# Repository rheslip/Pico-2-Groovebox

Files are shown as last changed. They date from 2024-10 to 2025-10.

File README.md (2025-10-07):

# Pico 2 Groovebox
 Sample player/groovebox based on RP2350

Oct 2025 - added step editor and .stl files for 3D printed enclosure. SD interface changed from SPI to SDIO which improved flie loading speed a lot. Tweeks to the sensitivity of some of the MPR121 keypad keys have been added. I had issues with keypresses being detected too easily or not at all. Still not completely resolved but much improved. Various other bug fixes and enhancements.

demo and tutorial https://www.youtube.com/watch?v=hEJh2LgJkRc&t=5s 
 
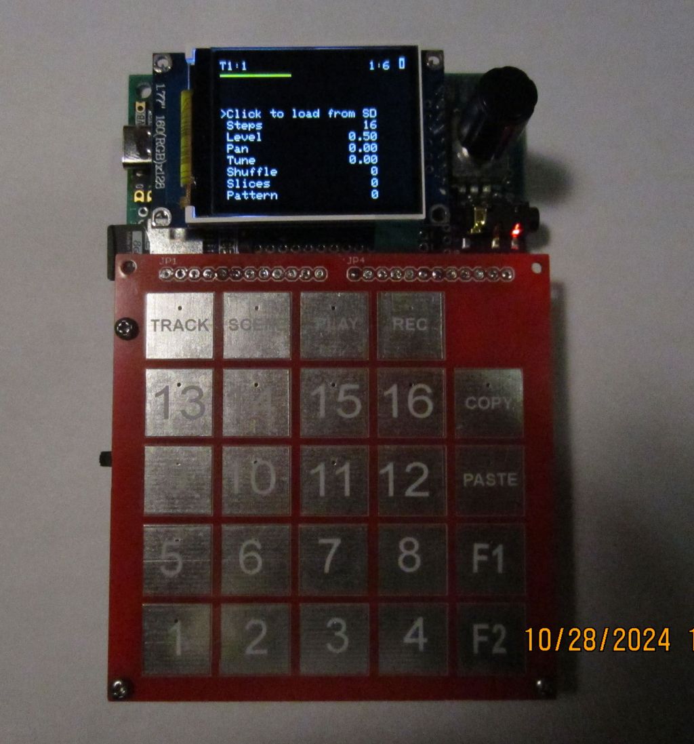
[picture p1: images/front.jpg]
Front
 
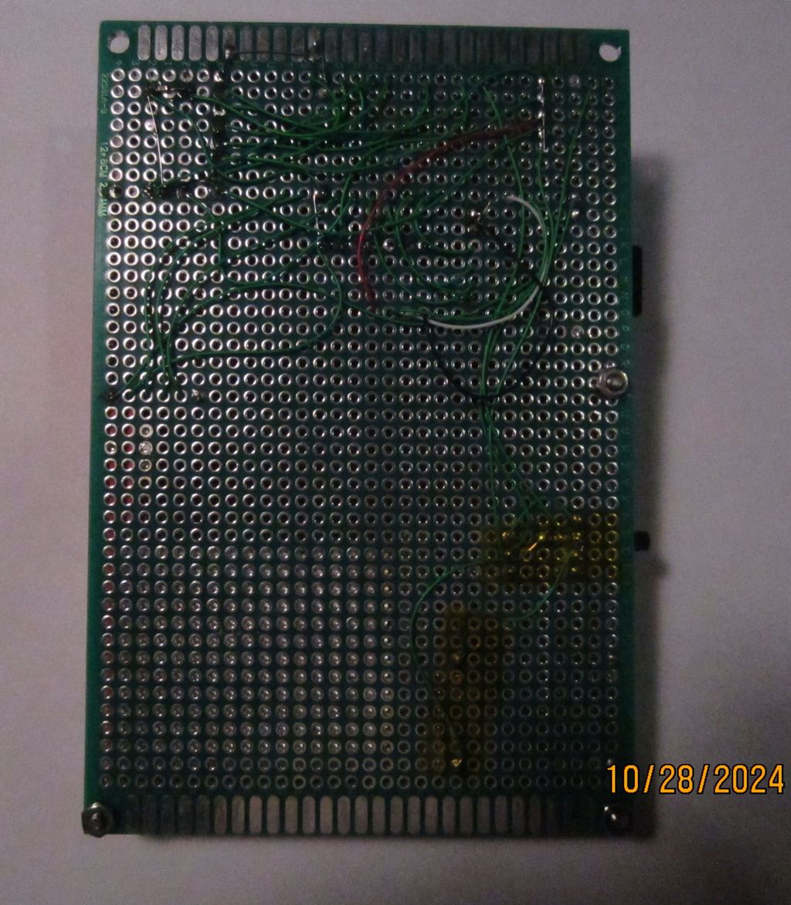
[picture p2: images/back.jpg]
Back
 
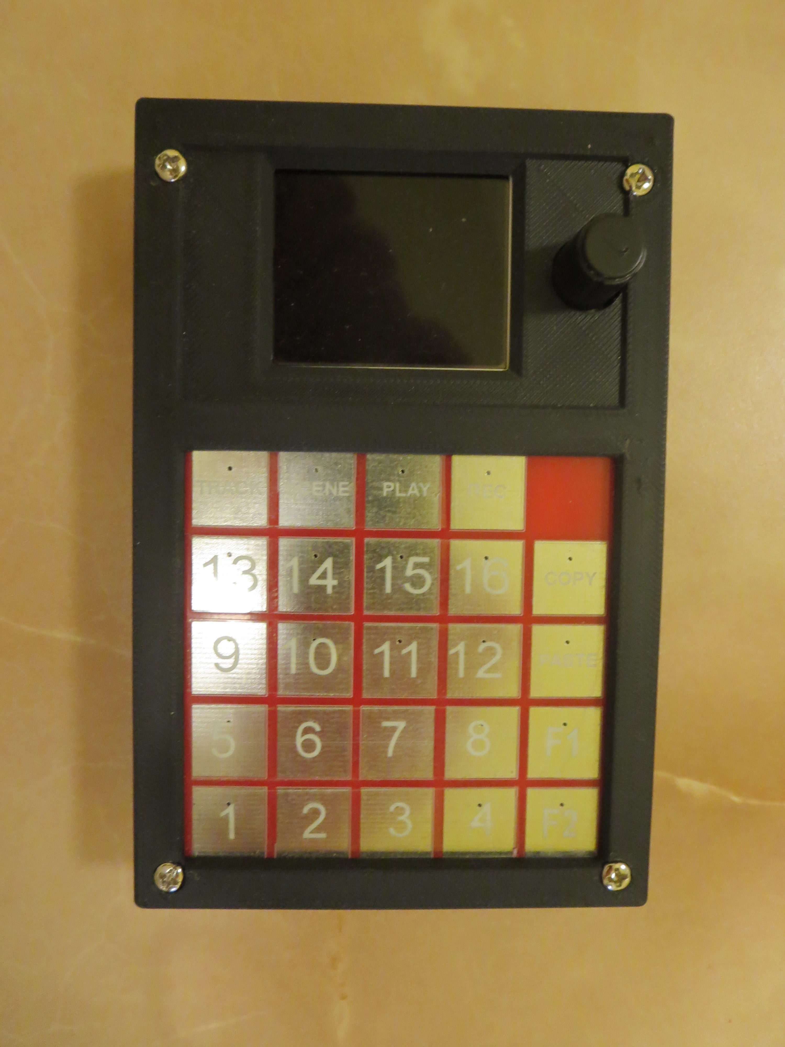
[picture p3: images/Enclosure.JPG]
New 3D Printed Enclosure
  
 
**Hardware components used**

Pimoroni Pico 2+ with 8mb PSRAM (for sample storage)

Generic PCM5102A DAC module from AliExpress

160x128 ST7735 color TFT display

Encoder with switch

24 pad touch keyboard PCB - gerbers are in the hardware directory. $4 including shipping for 5 PCBs from JLCPCB.com

2x MPR121 touch sensor modules from AliExpress

Micro SD breakout board **Note that the latest version of the code uses SDIO which is much faster**

**Optional:**

LiPo battery - I used 1500mah for approx 8 hours use

LiPo charger module from AliExpress

Power switch

3V to 5V stepup regulator from AliExpress

3d Printed Case - .stl files in the hardware section. Design is for a build on 80x120mm perfboard available on Aliexpress or Amazon. No doubt will need tweeking unless your layout is exactly like mine.

There is no schematic but it should be pretty obvious how to wire the modules to the RP2350 board if you look at IO.h in the source code.

**Overview**

Pico 2 Groovebox is a flexible sample player + groovebox with 16 tracks and 16 scenes. Samples can be oneshots or loops. You can play samples with the keypad, play loops, record clips and use drum trigger patterns. Each track has a sequencer which triggers a sample to play. Sequences can be from 1 to 128 steps but normally you would set tracks up as multiples of 16 steps (1 bar). 

It is helpful to think of tracks and scenes as a matrix with columns as tracks and rows as scenes. This setup is similar to Ableton and most grooveboxes. You can record a clip in every cell of this 16x16 matrix ie up to 144 clips, subject to memory limitation which is currently 512 total notes per track. 

The basic workflow is to select a track by holding the TRACK key and select the track using the number pads. Use the Track menus to load a .WAV file sample to a track from the SD card - this saves it in PSRAM for playback (SD is way too slow for direct playback). You can then record a clip (a sequence of sample triggers) by tapping the REC key and touching the the numbered keypads. Holding the REC key will erase the sequence. To change tracks hold the TRACK key and select another track using the number pads.

You can record up to 16 clips per track. Clips are organized by scenes ie rows of clips. Hold the SCENE key to select a scene using the number pads. Selecting a scene will launch all clips on that row of the clip matrix.

Tap the PLAY button to start or stop playback of all clips in the current scene. Hold the PLAY button to start playback in Song mode (described below).

When the sequencers are running you can play samples using the keypad to jam over the current scene, record sequences while the scene is playing, switch scenes and even record in song mode. 

Internally, clips are stored as MIDI sequences. I may consider adding MIDI I/O to the Pico 2 Groovebox so it could be used as a 16 channel MIDI recorder/sequencer.

**Track Screen and Menus**

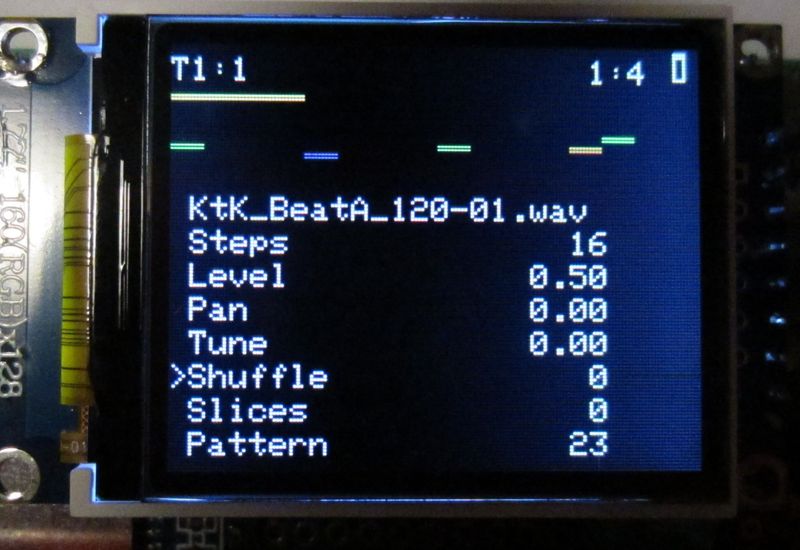
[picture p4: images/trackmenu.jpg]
trackmenu
 

The top line of the screen shows the currently selected Track:Scene, Song and Record indicators when enabled, and a Bar:Step indicator. On the far right is a simple battery level display.

Below that is a sequencer progress bar which indicates where the sequencer is. This is helpful when recording.

Below the progress bar is a small piano roll display showing the notes recorded on the track. If random velocities are enabled (see below) the color of the steps will range from Magenta (low velocity) to Red (highest velocities).

Below the piano roll is a parameter menu for each track for loading a sample, setting the track length in steps, setting the volume and pan, adjusting the tuning of the sample, adjusting the track shuffle timing, enabling or disabling sample slicing, and to adjust the pattern generator parameters.

**Setup Menu**

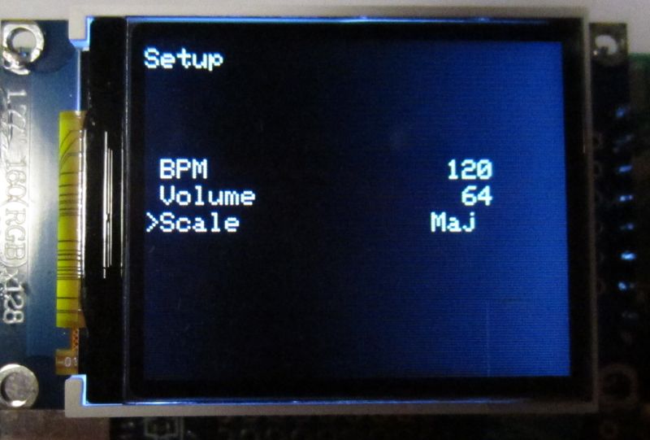
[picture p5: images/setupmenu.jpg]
setupmenu
 
 
Hold the TRACK key and turn the encoder to scroll through tracks 1-16. The first menu past track 16 is the Song chain menu (below). The next menu is Setup which allows selection of BPM, master volume and the musical scale to use on the numbered keys.

**Scales**

There are currently ten musical scales to select from. Selecting a scale changes the layout of the numbered keys. Key 9 plays the sample at its nominal pitch. Playing keys above key 9 will raise the pitch of the sample according to the selected scale. e.g. if the selected scale is chromatic each numbered key above 9 increases the pitch by one semitone. Likewise, keys below 9 reduce the pitch according to the selected scale.

Note that sample pitch and sample tuning are accomplished by a resampling algorithm so higher pitches will play for a shorter time and lower pitches become longer in duration. ie no timestretching going on here!

**Pattern Generator**

The pattern generator is an alternate way of loading trigger patterns into the sequencer. There are currently fifty three 16 bit trigger patterns organized from fewest triggers with pattern 0 having no triggers to pattern 53 which triggers on every sequencer step. Trigger patterns include some common drum patterns and some Euclidean patterns. If the sequencer length is longer than 16, the pattern will be repeated till the sequencer is full. If the sequencer length is less than 16 the trigger pattern will be shortened to the sequencer length. This is a handy way to chop a pattern off - shorten the sequence, load a trigger pattern and then lengthen the sequence.

The Pattern Shift parameter shifts the trigger pattern right one bit at a time, adding 16 more patterns to each of the basic trigger patterns.

The Pattern Offset parameter generates a series of random pitch offsets in the range selected in the menu. These offsets are added to the base note of the sample, quantized to the current scale and inserted into the sequencer. This results in a random melody in the current scale using the current pattern. 

The Level Offset parameter generates a series of random velocity offsets in the range selected in the menu. These offsets are added to velocity of the sample to give the sequence some random volume variations. The Level Offset parameter is scaled such that its maximum value (16) results in a random velocity range of 0 to 127.

The Autorandomizer parameter when "On" will re-randomize the pitch offsets and velocity offsets when the sequencer loops back to the first step. Huge fun when used with the sample slicer on loops!

Note that the pattern generator overwrites the sequencer clip with a new generated sequence when any of its parameters are changed. This means you can record more steps over a pattern but you can't add a pattern on top of a recorded clip.

**Step Editor**

The pattern step editor is accessed by pressing the F1 key - "Edit" will appear at the top of the display. A green cursor will appear under the first step on the piano roll. The number to the right of "Edit" is the step the cursor is on - rotate the encoder to change steps. To edit a step press the encoder - the cursor will turn red indicating we are entering or editing a note at this step. If there is no note at the step one will automatically be inserted with MIDI note 60 - the MIDI note number appears beside the step number at the top of the screen. Turn the encoder to change the note pitch (+-1 octave). To remove a note, turn the encoder until the note dissappears off the top or bottom of the piano roll display. Press the encoder to exit note entry mode. Press F1 again to exit the step editor. 

**Clip/Scene Cut and Paste**

To copy a clip, press the Copy key while that clip is on the screen. Select a different clip (using Track and or Scene keys as above) and press the Paste key to copy the sequence to that clip.

To copy an entire scene, hold the Scene key and press the Copy key to copy the current scene. Select a new scene using the Scene key and the numbered keys and press Paste to paste into the new scene.

**Sample Slicer**

The Slices parameter in the track menu controls if slicing is off (slices=0) or the number of uniform sample slices to use up to a maximum of 16. Sample slices are mapped to the numbered keys - if the number of slices is less than 16 the slice pattern repeats over the numbered keys. Slices can be played on the keypad, recorded as a clip or sequenced with the pattern generator. If using the pattern generator, the Sample Offset is used to select which sample is played on active sequencer steps. ie if Sample Offset is 0, the pattern will only include the first slice, if Sample Offset is 1 it will randomly include slice 0 or slice 1 etc.

Sample Slicer + Pattern Generator Autorandomizer = a lot of fun! 

**Song Chain**

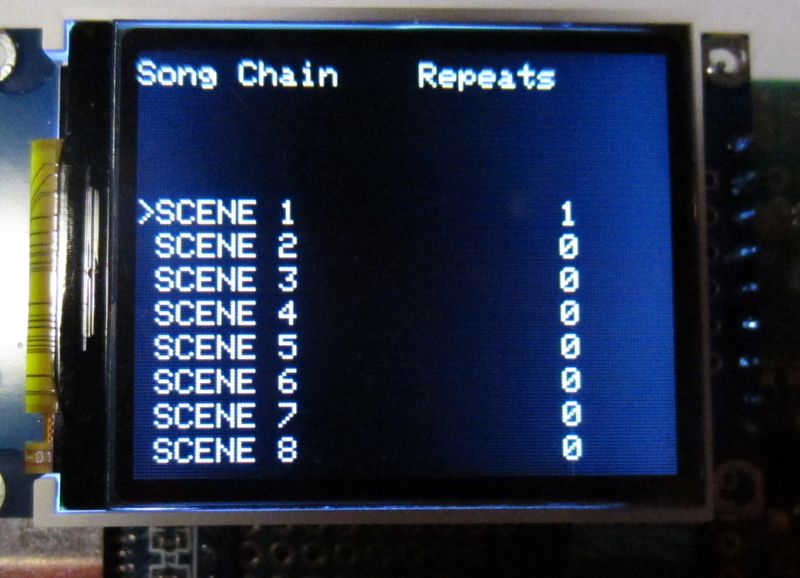
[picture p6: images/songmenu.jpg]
songmenu
 
 
As described above, the first menu when scrolling past track 16 is the Song Chain. The Song Chain is a list of scenes and the number of repeats for each  scene. By default all scene counts are 0 except for Scene 1 which will always have a minimum repeat count of 1. A song chain is set up by selecting the number of times you would like each scene to repeat. If the count is 0, that scene is skipped. At the the end of the chain the song will restart at Scene 1. To play the song, hold the Play key until the "SONG" indicator on the top line of the display is on. To turn song mode off, hold the Play key until the "SONG" indicator goes off.

Note: In song mode, a scene is completed/counted down when ALL clips arrive on the last step at the same time. e.g. if one of the tracks is set to a sequence length of 64 and the others are 16 steps, the other tracks will be repeated 4 times and when the 64 step sequence ends the scene counter will be counted down. If we have a track with a sequence length of 16 and another with a length of 15, it will take 16 iterations for the two tracks to arrive at the last step at the same time. If you add another track with 14 steps, its going to take a long time for them to all arrive at the last step at the same time! In general you should keep sequence lengths multiples of 16 or 1 bar.

**A Word on SD Cards**

I don't think its mandatory for micro SD card to work with a SPI interface. I have a small assortment of 4gb, 8gb and 16gb micro SD cards and very few of them seem to work with SPI. **Note that the latest version of the code uses SDIO to access the SD card**. Make sure the card is formatted as FAT16 or FAT32. All samples **MUST** be under a directory in the root named "Samples". As mentioned before it is suggested you organize your samples in subdirectories with no more than 50 or so samples to keep loading time to a minimum. The maximum path length is 200 characters so don't go too crazy on the directory and sample name lengths.

**FAQ**

How do you compile the source? I used arduino 2.3.2 with Arduino Pico v 4.1. You will need Adafruit graphics library, the ST 7735 driver, and probably some other libs I've forgotten. The rest of the stuff is in the source tree. I started with the Adafruit FifteenStep MIDI recorder library but I had to modify it a lot so I renamed it SixteenStep and its included in the library directory.

Why not have sequencer length set up in bars? I debated this and actually had it set up with bars at one point. I opted for the flexibility of having sequences be any length (up to 128). Its useful for ambient stuff or jamming when you want things to sound similar but not repeat exactly. Set two drum tracks to different lengths for example and the rhythm will change as the beats change relative to each other on every loop.

Why the pattern generator? I had it set up as just a recorder and then quickly realized its hard (for me anyway) to play the pads to record exactly on step 1, which you want if you have multiple scenes (so scene changes are in sync). The pattern generator makes it easy to place triggers where you want them and relative to each other.

Is the code stable? Not completely. It crashes now and then but I've used it for hours on end with no glitches. Still working on those pesky bugs...

Why is loading files so slow? **Its MUCH better with the new SDIO interface**. Still not as fast as I'd like but very usable.

What file formats will it read? 16 and 24 bit, 44hkz, 22khz, stereo or mono .WAV files. It converts everything to 22khz mono internally. I suggest you organize your samples into directories with no more than 50 or so samples per directory to minimize loading time.

Why do you use 22khz mono internally? To minimize memory use. With 8mbytes RAM you can load about 190 seconds of 22khz mono samples vs only 47 seconds with 44khz stereo. Use the pan control for fake stereo - it actually sounds really good even at 22khz.

Why don't you do a PCB? It would probably have to be two boards to work mechanically. I'm not that great at PCB layout - maybe somebody else would take this on if I do a schematic in Kicad?

What are the F1 and F2 keys for? TBD. I'm thinking of adding some more features like track mute and solo

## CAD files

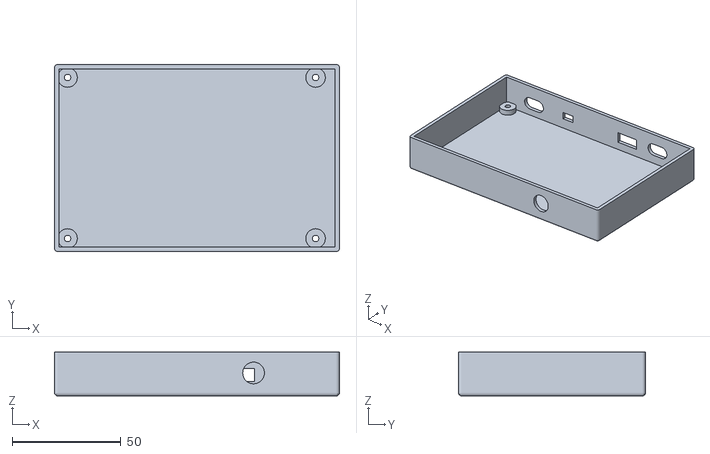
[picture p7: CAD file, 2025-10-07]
hardware/Enclosure/Base.stl
131.0 x 86.0 x 20.2

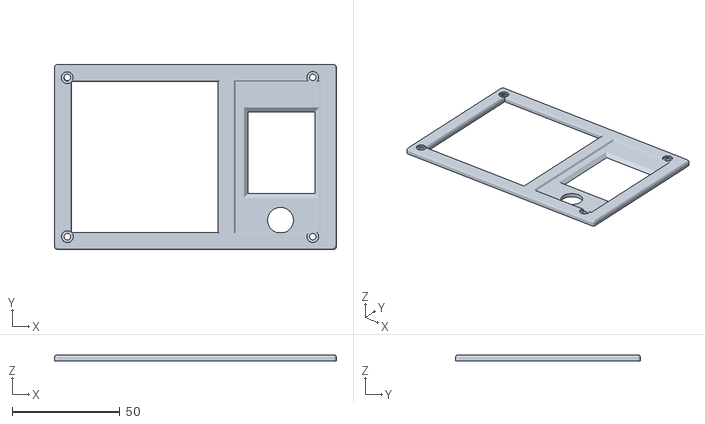
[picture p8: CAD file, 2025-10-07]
hardware/Enclosure/Top.stl
131.0 x 86.0 x 3.00

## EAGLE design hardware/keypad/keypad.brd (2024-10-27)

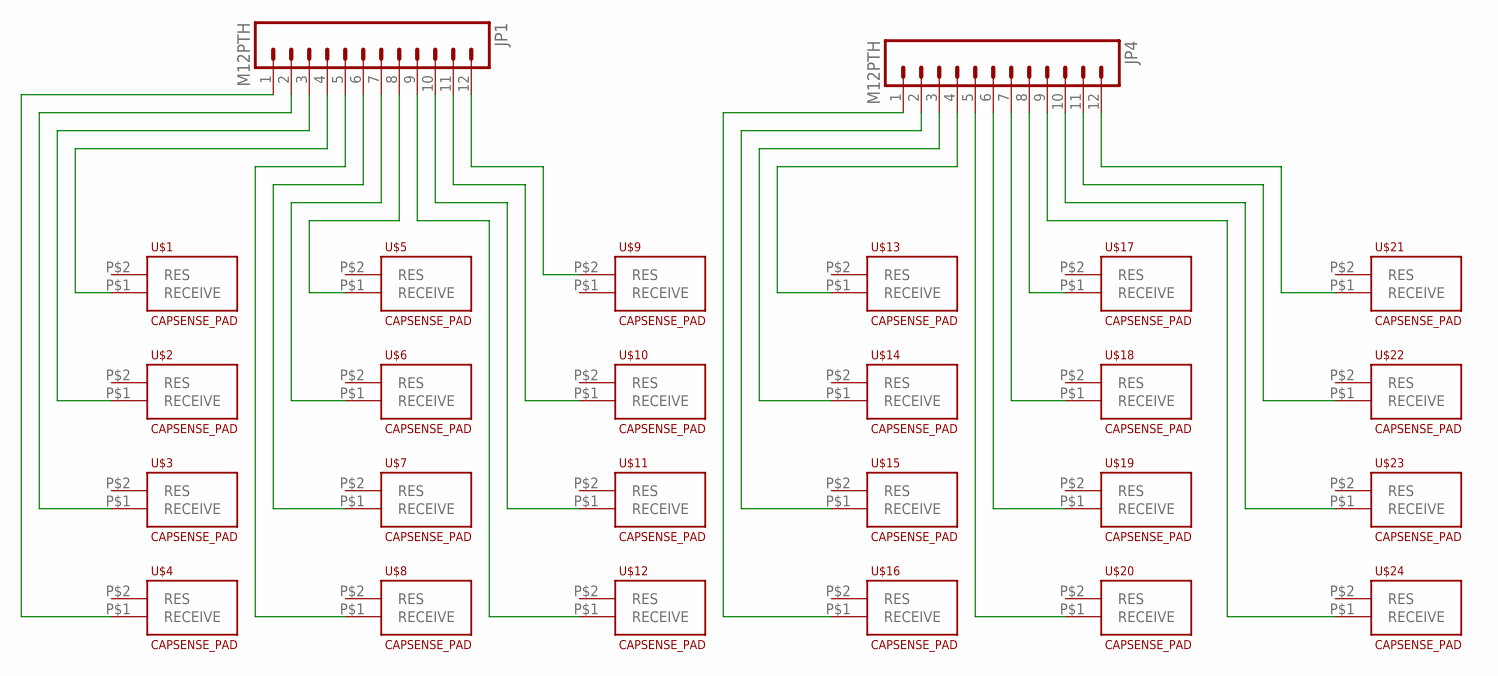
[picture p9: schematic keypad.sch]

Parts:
JP1, JP4: M12PTH; 1X12
U$1, U$2, U$3, U$4, U$5, U$6, U$7, U$8, U$9, U$10, U$11, U$12, U$13, U$14, U$15, U$16, U$17, U$18, U$19, U$20, U$21, U$22, U$23, U$24: CAPSENSE_PAD

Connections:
unnamed: JP1.1, U$4.P$1 (RECEIVE)
unnamed: JP1.2, U$3.P$1 (RECEIVE)
unnamed: JP1.3, U$2.P$1 (RECEIVE)
unnamed: JP1.4, U$1.P$1 (RECEIVE)
unnamed: JP1.5, U$8.P$1 (RECEIVE)
unnamed: JP1.6, U$7.P$1 (RECEIVE)
unnamed: JP1.7, U$6.P$1 (RECEIVE)
unnamed: JP1.8, U$5.P$1 (RECEIVE)
unnamed: JP1.9, U$12.P$1 (RECEIVE)
unnamed: JP1.10, U$11.P$1 (RECEIVE)
unnamed: JP1.11, U$10.P$1 (RECEIVE)
unnamed: JP1.12, U$9.P$2 (RES)
unnamed: JP4.1, U$16.P$1 (RECEIVE)
unnamed: JP4.2, U$15.P$1 (RECEIVE)
unnamed: JP4.3, U$14.P$1 (RECEIVE)
unnamed: JP4.4, U$13.P$1 (RECEIVE)
unnamed: JP4.5, U$20.P$1 (RECEIVE)
unnamed: JP4.6, U$19.P$1 (RECEIVE)
unnamed: JP4.7, U$18.P$1 (RECEIVE)
unnamed: JP4.8, U$17.P$1 (RECEIVE)
unnamed: JP4.9, U$24.P$1 (RECEIVE)
unnamed: JP4.10, U$23.P$1 (RECEIVE)
unnamed: JP4.11, U$22.P$1 (RECEIVE)
unnamed: JP4.12, U$21.P$1 (RECEIVE)

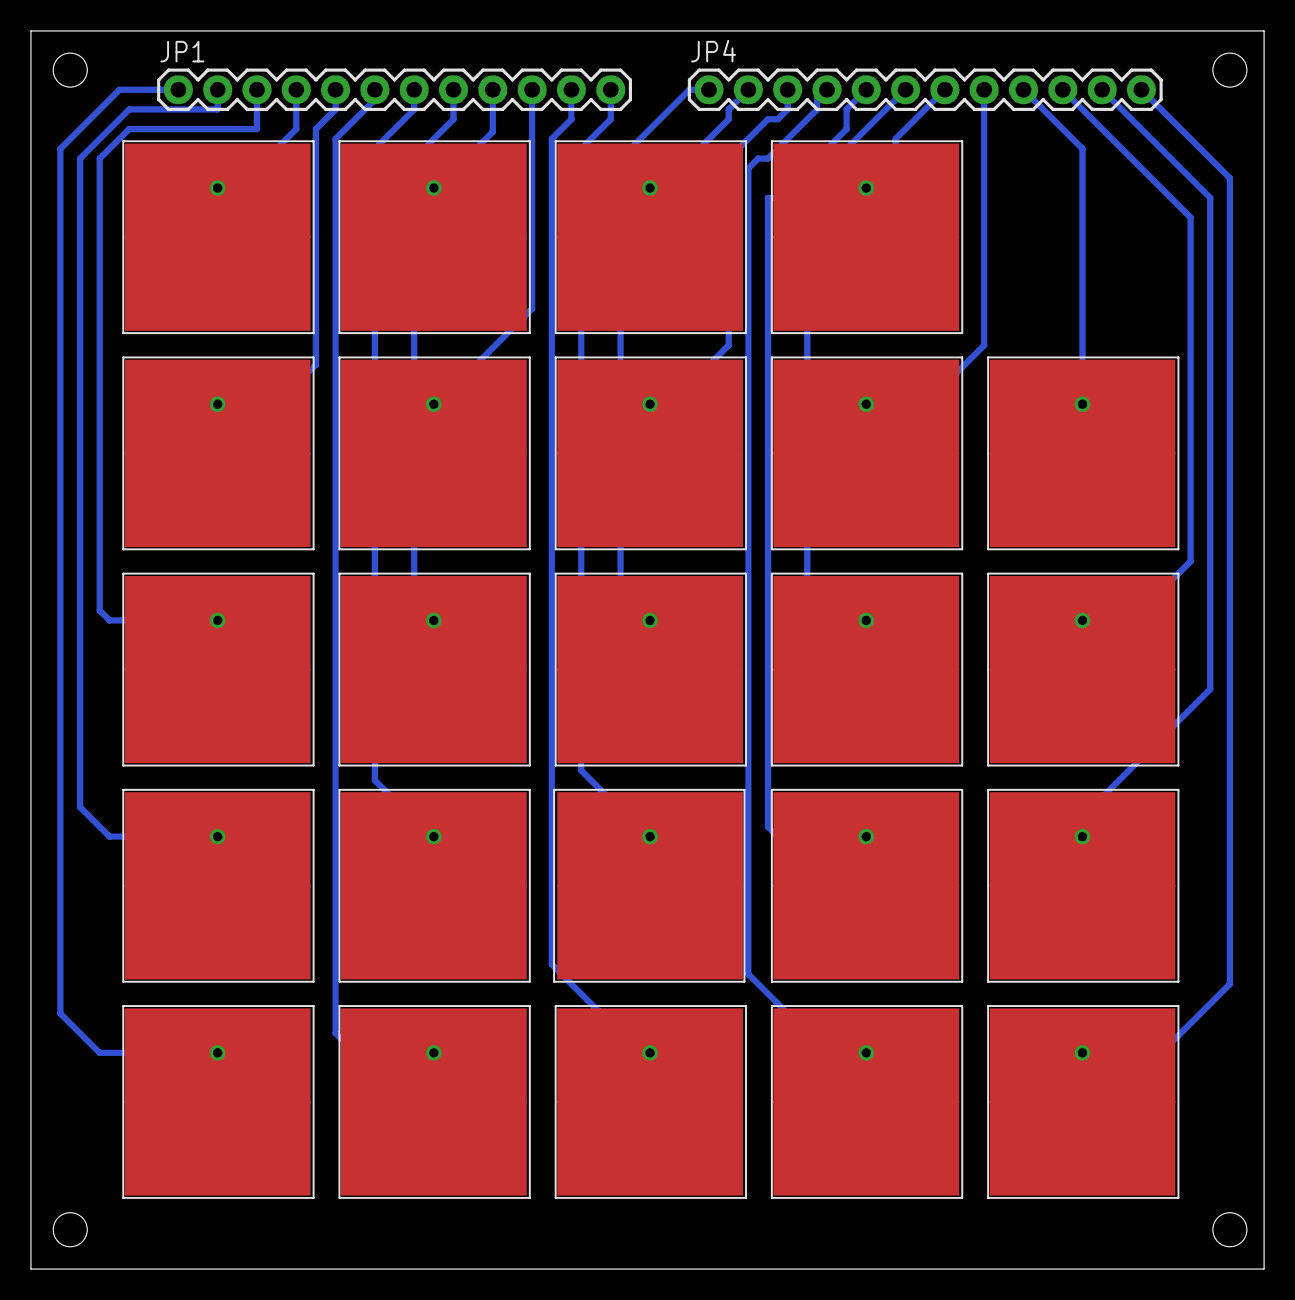
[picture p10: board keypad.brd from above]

Board: 2 copper layers, 79.7 x 80.0 mm, 26 parts (0 on the bottom side), 24 nets.

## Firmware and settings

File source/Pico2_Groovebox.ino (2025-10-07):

// Copyright 2019 Rich Heslip
//
// Author: Rich Heslip 
//
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
// See http://creativecommons.org/licenses/MIT/ for more information.
//
// -----------------------------------------------------------------------------
//
// 
// sample player/looper inspired by Jan Ostman's ESP8266 drum machine http://janostman.wordpress.com
// will play a 22khz sample file converted to a header file in the appropriate format
// Feb 3/19 - initial version on ESP8266
// Jan 2023 - ported code to Pi Pico so I can use it on a 16mb flash version
// July 24 - this version modded to run on my new groovebox HW - added recording, tracks, scenes, song mode, sample slicing etc
// Sept 2024 - ported to Pimoroni Pico 2 + board with 8mb PSRAM and SD card - can load samples from SD now. 160x128 Color TFT display. added a per track pattern generator

#include <Arduino.h> 

//#include <WiFi.h>
//#include <i2s.h>
//#include <i2s_reg.h>
//#include <pgmspace.h>
//#include "driver/i2s.h"
//#include "freertos/queue.h"
#include <Wire.h>
#include "SdFat.h"
#include "sdios.h"

#include <SPI.h>
//#include <SD.h>

#include <Adafruit_GFX.h>
#include <Adafruit_ST7735.h> // Hardware-specific library for ST7735
//#include <Adafruit_SSD1306.h>
//#include <SH1106.h>
//#include "MIDI.h"
#include "io.h"
#include <I2S.h>
//#include "RPi_Pico_TimerInterrupt.h" // fails on RP2350 after a while
#include <hardware/timer.h>
#include <hardware/irq.h>
#include "Clickencoder.h"
#include "Adafruit_MPR121.h"
#include "SixteenStep.h"
#include "pico/multicore.h"
#include "drumpatterns.h"

#define DEBUG // to get serial debug info

#ifndef _BV
#define _BV(bit) (1 << (bit)) 
#endif

// Try to select the best SD card configuration.
#if defined(HAS_TEENSY_SDIO)
#define SD_CONFIG SdioConfig(FIFO_SDIO)
#elif defined(RP_CLK_GPIO) && defined(RP_CMD_GPIO) && defined(RP_DAT0_GPIO)
// See the Rp2040SdioSetup example for RP2040/RP2350 boards.
#define SD_CONFIG SdioConfig(RP_CLK_GPIO, RP_CMD_GPIO, RP_DAT0_GPIO)
#elif ENABLE_DEDICATED_SPI
#define SD_CONFIG SdSpiConfig(SD_CS_PIN, DEDICATED_SPI, SPI_CLOCK)
#else  // HAS_TEENSY_SDIO
#define SD_CONFIG SdSpiConfig(SD_CS_PIN, SHARED_SPI, SPI_CLOCK)
#endif  // HAS_TEENSY_SDIO


// SD_FAT_TYPE = 0 for SdFat/File as defined in SdFatConfig.h,
// 1 for FAT16/FAT32, 2 for exFAT, 3 for FAT16/FAT32 and exFAT.
#define SD_FAT_TYPE 3

#if SD_FAT_TYPE == 0
SdFat sd;
File file;
#elif SD_FAT_TYPE == 1
SdFat32 sd;
File32 file;
#elif SD_FAT_TYPE == 2
SdExFat sd;
ExFile file;
#elif SD_FAT_TYPE == 3
SdFs sd;
FsFile file;
#else  // SD_FAT_TYPE
#error Invalid SD_FAT_TYPE
#endif  // SD_FAT_TYPE

// Try max SPI clock for an SD. Reduce SPI_CLOCK if errors occur.
//#define SPI_CLOCK SD_SCK_MHZ(50)
// #define SPI_CLOCK SD_SCK_MHZ(25)

#define MONITOR_CPU1  // define to enable 2nd core monitoring
//#define HW_DEBUG  // for debug pin usage

//Adafruit_SH1106 display(OLED_DC, OLED_RESET, OLED_CS);
Adafruit_ST7735 display = Adafruit_ST7735(TFT_CS, TFT_RS, TFT_RESET);
#define WHITE ST77XX_WHITE
#define BLACK ST77XX_BLACK
#define RED ST77XX_RED
#define RED2 0xF804
#define LIGHTGREEN 0x03e0
#define GREEN ST77XX_GREEN
#define BLUE ST77XX_BLUE 
#define CYAN ST77XX_CYAN
#define MAGENTA ST77XX_MAGENTA
#define YELLOW ST77XX_YELLOW
#define ORANGE ST77XX_ORANGE


#define PSRAM_ADDR 0x11000000
#define PSRAM_SIZE 0x00800000  // 8 Mbytes

//#define SAMPLERATE 11025 
#define SAMPLERATE 22050
//#define SAMPLERATE 44100
#define PMALLOC_CHUNK 131072 // hopefully minimizes memory fragmentation 

#define MIDDLE_C 60 // MIDI note for middle C
#define HIGHEST_NOTE 76 // upper note for editor
#define LOWEST_NOTE 43 // lower note for editor
#define NOTE_DEADZONE 4 // range of notes above highest and below lowest that will result in note being turned off in editor
#define DEFAULT_LEVEL 64  // default MIDI velocity

#define NTRACKS 16  // 
#define NSCENES  16 // works best with the keypad
#define NUM_VOICES NTRACKS
#define MAX_STEPS FS_MAX_STEPS // max number of notes per sequencer
#define SEQUENCER_MEMORY 2048  // memory per sequencer (bytes)
//#define SEQUENCER_MEMORY sizeof(SixteenStepNote)*MAX_STEPS // FifteenStep can record polyphonic but not using that 
#define STEPS_PER_BAR 16
#define TEMPO    120 // default tempo
#define CLIPS_COMPLETE ((1<<NSCENES)-1) // bitmap of clips that are on last step

// Keeps track of the last pins touched
// so we know when buttons are released
uint32_t lasttouched = 0;
uint32_t currtouched = 0;
#define RECBUTTON_HOLD_TIME 500 // time in ms for rec button hold to erase
#define TRANSPORT_BUTTON_HOLD_TIME 500 // time in ms for play button hold to start song mode

// remap pads from MPR121 readings which are not in order to desired keypad position
// top row - track,scene, start/stop, record
// next 4 rows x 4 columns keypad 0-15
// right column copy, paste
// ** note to self - uncomment the pad number code in loop() below and press PAD0 (Number pad 1) and enter its bit number as the definition for PAD0. etc etc
#define NPADS 24 // total number of pads on keypad
/*
#define PAD0 4   // pad 0 (ie number pad 1) as detected by MPR121
#define PAD1 9
#define PAD2 14
#define PAD3 19
#define PAD4 2
#define PAD5 7
#define PAD6 12
#define PAD7 17
#define PAD8 1
#define PAD9 6
#define PAD10 11
#define PAD11 16
#define PAD12 0
#define PAD13 5
#define PAD14 10
#define PAD15 15 // last number pad
*/
#define PAD0 0   // pad 0 (ie number pad 1) as detected by MPR121
#define PAD1 5
#define PAD2 10
#define PAD3 15
#define PAD4 1
#define PAD5 6
#define PAD6 11
#define PAD7 16
#define PAD8 2
#define PAD9 7
#define PAD10 12
#define PAD11 17
#define PAD12 4
#define PAD13 9
#define PAD14 14
#define PAD15 19 // last number pad
#define PAD16 3  // track
#define PAD17 8  // scene
#define PAD18 13 // play/stop
#define PAD19 18 // record
#define PAD20 20 // copy
#define PAD21 21 // paste
#define PAD22 22
#define PAD23 23 // shift

// maps MPR121 number to desired keypad
// note to self - this is the PAD numbers above in order of #define value
//uint8_t padmap[NPADS] = {12,8,4,0,16,13,9,5 ,1,17,14,10,6,2,18,15, 11,7,19,3,23,22,21,20}; 
//uint8_t padmap[NPADS] = {12,8,4,16,0,13,9,5 ,17,1,14,10,6,18,2,15, 11,7,19,3,20,21,22,23}; // for number pads with 1 top left
uint8_t padmap[NPADS] = {0,4,8,16, 12,1,5,9 ,17,13,2,6, 10,18,14,3, 7,11,19,15, 20,21,22,23};   // for number pads with 1 bottom left

// button masks
// button is the bit in the combined MPR121 keypad outputs
#define TRACK_BUTTON _BV(PAD16) // press to select track
#define SCENE_BUTTON _BV(PAD17) // press to select scene
#define TRANSPORT_BUTTON _BV(PAD18) // play/stop, double click for song mode
#define RECORD_BUTTON _BV(PAD19) // record, hold to delete
#define COPY_BUTTON _BV(PAD20)   // copy clip
#define PASTE_BUTTON _BV(PAD21)  // paste clip
#define EDIT_BUTTON _BV(PAD22)
#define SHIFT_BUTTON _BV(PAD23)
#define KEY1        _BV(PAD0) // number pads
#define KEY2        _BV(PAD1)
#define KEY3        _BV(PAD2)
#define KEY4        _BV(PAD3)
#define KEY5        _BV(PAD4) // number pads
#define KEY6        _BV(PAD5)
#define KEY7        _BV(PAD6)
#define KEY8        _BV(PAD7)
#define KEY9        _BV(PAD8) // number pads
#define KEY10        _BV(PAD9)
#define KEY11        _BV(PAD10)
#define KEY12        _BV(PAD11)
#define KEY13        _BV(PAD12) // number pads
#define KEY14        _BV(PAD13)
#define KEY15        _BV(PAD14)
#define KEY16        _BV(PAD15)

// mask to detect any number keypress
#define KEYSMASK (KEY1|KEY2|KEY3|KEY4|KEY5|KEY6|KEY7|KEY8|KEY9|KEY10|KEY11|KEY12|KEY13|KEY14|KEY15|KEY16)

// globals
int16_t bpm = TEMPO;
int16_t shuffle[NTRACKS]={0,0,0,0,0,0,0,0,0,0,0,0,0,0,0,0,}; // swing/shuffle amount for each track 0-15
int16_t pattern[NTRACKS]={0,0,0,0,0,0,0,0,0,0,0,0,0,0,0,0,}; // pattern from drumpatterns.h
int16_t patshift[NTRACKS]={0,0,0,0,0,0,0,0,0,0,0,0,0,0,0,0,}; // pattern shift
int16_t patpitch[NTRACKS]={0,0,0,0,0,0,0,0,0,0,0,0,0,0,0,0,}; // pattern note offsets
int16_t patvelocity[NTRACKS]={0,0,0,0,0,0,0,0,0,0,0,0,0,0,0,0,}; // pattern velocity offsets
int16_t tracklevel[NTRACKS] = {500,500,500,500,500,500,500,500,500,500,500,500,500,500,500,500}; // track volume 
int16_t trackpan[NTRACKS] = {0,0,0,0,0,0,0,0,0,0,0,0,0,0,0,0,};  // track pan
uint32_t seqmillis; // millis() time to pass to sequencers

int8_t pitchoffsets[NTRACKS][MAX_STEPS]; // random values for pitch pattern

int8_t velocityoffsets[NTRACKS][MAX_STEPS]; // random values for velocity offset

// sequencer modes
bool record_mode = false;
bool play_mode = true;
bool song_mode = false;
bool edit_mode=false;
bool Copybutton, Pastebutton; // button down flags
bool shiftkey; // shift key state
uint16_t clip_complete,clipflags; // bitmap of sequencers that have just completed last step
//int16_t steps[NTRACKS] = { 16,16,16,16,16,16,16,16,16,16,16,16,16,16,16,16}; // steps for each track
int16_t steps[NTRACKS] = { 16,16,16,16,16,16,16,16,16,16,16,16,16,16,16,16}; // steps for each track
int16_t scenecount[NSCENES] = {1,0,0,0,0,0,0,0,0,0,0,0,0,0,0,0};  // how many times to repeat scene in song mode - values changed in song menu
int16_t rerandomize[NTRACKS] = {0,0,0,0,0,0,0,0,0,0,0,0,0,0,0,0};  // when true re-randomize notes and velocities at end of scene
uint8_t track=0;  // current track in UI
int16_t scene=0; // the current scene 
int16_t scenecounter=0; // counts down scene repeats 

int16_t sequencer=0; // the sequencer currently running
int16_t current_step=0;
int16_t last_step=0; // so we can tell when the sequencer advanced
int16_t last_scene=0; // so we can tell when the song scene sequencer advanced
int16_t stepsperbar=STEPS_PER_BAR; // used by the UI to show bar:step
int16_t current_scale=1; // musical scale in use
int16_t master_volume = 64;
int16_t shift=0; // shift flag used by menu system 0= shift back, 1 = shift right
int16_t clipbuffercnt =0; // current size of clip buffer (in notes)
SixteenStepNote clipbuffer[MAX_STEPS]; // buffer used for clip copy/paste
SixteenStepNote scenebuffer[NTRACKS][MAX_STEPS]; // buffer used for scene copy/paste

// sequencer per track allows tracks to have different lengths and it allows clearing each track individually
// more overhead but its a lot more flexible
SixteenStep seq[NTRACKS] = { 
  SixteenStep(SEQUENCER_MEMORY), // MIDI recorder/sequencer
  SixteenStep(SEQUENCER_MEMORY),
  SixteenStep(SEQUENCER_MEMORY),
  SixteenStep(SEQUENCER_MEMORY),
  SixteenStep(SEQUENCER_MEMORY),
  SixteenStep(SEQUENCER_MEMORY),
  SixteenStep(SEQUENCER_MEMORY),
  SixteenStep(SEQUENCER_MEMORY),
  SixteenStep(SEQUENCER_MEMORY), // MIDI recorder/sequencer
  SixteenStep(SEQUENCER_MEMORY),
  SixteenStep(SEQUENCER_MEMORY),
  SixteenStep(SEQUENCER_MEMORY),
  SixteenStep(SEQUENCER_MEMORY),
  SixteenStep(SEQUENCER_MEMORY),
  SixteenStep(SEQUENCER_MEMORY),
  SixteenStep(SEQUENCER_MEMORY),
};

I2S DAC(OUTPUT);  // using PCM1103 stereo DAC

Adafruit_MPR121 padA = Adafruit_MPR121(); // touch keyboard used for note entry
Adafruit_MPR121 padB = Adafruit_MPR121(); // touch keyboard used for note entry


// chromatic pitch table - maps a midi note to a 12 bit pitch step - see voices below for how pitch step works
uint32_t pitchtable[128]= {
128,136,144,152,161,171,181,192,203,215,228,242,
256,271,287,304,323,342,362,384,406,431,456,483,
512,542,575,609,645,683,724,767,813,861,912,967,
1024,1085,1149,1218,1290,1367,1448,1534,1625,1722,1825,1933,
2048,2170,2299,2435,2580,2734,2896,3069,3251,3444,3649,3866,
4096,4340,4598,4871,5161,5468,5793,6137,6502,6889,7298,7732,
8192,8679,9195,9742,10321,10935,11585,12274,13004,13777,14596,15464,
16384,17358,18390,19484,20643,21870,23170,24548,26008,27554,29193,30929,
32768,34716,36781,38968,41285,43740,46341,49097,52016,55109,58386,61858,
65536,69433,73562,77936,82570,87480,92682,98193,104032,110218,116772,123715,
131072,138866,147123,155872,165140,174960,185364,196386
};

// table maps pads to MIDI note numbers - pad 9 is middle C. 
// rows are scales: CHROMATIC,MAJOR,MINOR,HARMONIC_MINOR,MAJOR_PENTATONIC,MINOR_PENTATONIC,DORIAN,PHRYGIAN,LYDIAN,MIXOLYDIAN
uint8_t padtoMIDI[10][16] = {
52,53,54,55,56,57,58,59,60,61,62,63,64,65,66,67, // chromatic
47,48,50,52,53,55,57,59,60,62,64,65,67,69,71,72, // major
48,50,51,55,53,55,56,58,60,62,63,65,67,68,70,72, // minor 0b10110101101
47,48,50,51,53,55,56,59,60,62,63,65,67,68,71,72, // harmonic minor
40,43,45,48,50,52,55,57,60,62,64,67,69,72,74,76, // major penta
41,43,46,48,51,53,55,58,60,63,65,67,70,72,75,77,  // minor penta
46,48,50,51,53,55,57,58,60,62,63,65,67,69,70,72,  // dorian
46,48,49,51,53,55,56,58,60,61,63,65,67,68,70,72, // phrygian
47,48,50,52,54,55,57,59,60,62,64,66,67,69,71,72, // lydian
46,48,50,52,53,55,57,58,60,62,64,65,67,69,70,72, // mixolydian
};


// maps random pitch offsets so they can be quantized to scale
// ie as we increase pitch offsets we want to add more notes above and below the root note
uint8_t pitchremap[NPADS]= {8,7,9,6,10,5,11,4,12,3,13,2,14,1,15,0};

// maps velocity levels to colors
uint16_t vcolors[8] = {MAGENTA,CYAN,BLUE,LIGHTGREEN,GREEN,ORANGE,YELLOW,RED};


/* no MIDI for now
// MIDI stuff
uint8_t MIDI_Channel=10;  // default MIDI channel for percussion
struct SerialMIDISettings : public midi::DefaultSettings
{
  static const long BaudRate = 31250;
};


// must use HardwareSerial for extra UARTs
HardwareSerial MIDISerial(2);

// instantiate the serial MIDI library
MIDI_CREATE_CUSTOM_INSTANCE(HardwareSerial, MIDISerial, MIDI, SerialMIDISettings);
*/
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
void loop() {
  float pitch, retune;
  static uint32_t recbutton_timer,transportbutton_timer;
  static bool trackerased,startsongmode;


  if (edit_mode) editnotes();  // note editor needs encoder so its mutually exclusive from menus
  else  domenus();

  // first 16 menu pages are track/voice settings which have extra elements on screen
  if (topmenuindex < NTRACKS) {
    track = topmenuindex; // map menu index to track/voice number
    if (last_step != current_step) { // sequencer has advanced so update display
      showposition(current_step);  // moved this out of the sequencer callback to reduce display overhead
      last_step=current_step;
    }
    if (last_scene != scene) { // scene sequencer has advanced so update piano roll display
      showpattern(track);  // 
      last_scene=scene;
    }
  }

// re-randomize at end of scene if user has selected to in menus
  if (clipflags!=clip_complete) {  
    uint16_t clips=clip_complete;  // bitmap of clips that just completed
    for (int16_t t=0; t<NTRACKS; ++t) {
      if ((clips & 1) && rerandomize[t] ) {  // find clips that just ended
        for (int16_t s=0;s<steps[t];++s) {
          pitchoffsets[t][s]=random(0,patpitch[t]+1);
          velocityoffsets[t][s]=constrain(random(-(patvelocity[t]*4),patvelocity[t]*4),0,128);
        }
        uint16_t pat,mask;  // this is just a copy of setpattern() code but it doesn't use the "track" global
        int16_t step;
        seq[t].removeNotes(scene <<4 | t); // clear scene contents
        pat=rightRotate(patshift[t],drumpatterns[pattern[t]],STEPS_PER_BAR); // rotate the pattern per the menu setting
        step=0;
        mask=0x8000;
        for (int n=0; n < steps[t]; ++n) {
          if ((pat & mask) !=0) { 
            if (voice[t].slices !=0) seq[t].setNote(n,scene <<4 | t,MIDDLE_C+pitchoffsets[t][n],DEFAULT_LEVEL+velocityoffsets[t][n]); // if pattern bit is set insert slice number
            else seq[t].setNote(n,scene <<4 | t,padtoMIDI[current_scale][pitchremap[pitchoffsets[t][n]]],DEFAULT_LEVEL+velocityoffsets[t][n]); // else insert note from current scale
          }
          mask=mask>>1;
          ++step;
          if (step == STEPS_PER_BAR) {
            step=0; // end of pattern, repeat
            mask=0x8000;
          }
        }
        if (t == track)showpattern(track); 
      }
      clips=clips>>1;
    }
    clipflags=clip_complete; // so we wait for next change
  }

// handle touch pad used for note entry, track and scene selection

  currtouched = padA.touched() | (padB.touched()<<(NPADS/2)); // combine both pads

// process the edit key
  if ((currtouched & EDIT_BUTTON)  && !(lasttouched & EDIT_BUTTON)) {
    edit_mode=!edit_mode; // toggle note editor on/off
    if (edit_mode) {
      song_mode=false; // can't edit in song mode
      editstate=INIT_EDITOR;  // reset editor state machine
    }
    else {
      eraseeditcursor(editcursorX);
      Encoder1.getButton(); // resets encoder button state which may not have been read
    }
  }

// save shift key state
  if (currtouched & SHIFT_BUTTON) shiftkey=true;
  else shiftkey=false;

// process play/stop/song mode button
  if ((currtouched & TRANSPORT_BUTTON) && !(lasttouched & TRANSPORT_BUTTON)) {  // transport button pressed, start timing
    transportbutton_timer=millis();
    startsongmode=false;
  }
  uint32_t tholdtime=millis()-transportbutton_timer;
  if ((currtouched & TRANSPORT_BUTTON) && (tholdtime > TRANSPORT_BUTTON_HOLD_TIME) && !startsongmode) { //transport button held
      song_mode=!song_mode;
      if (song_mode) {
   //     play_mode=false; // stop playing  
        stop_sequencers(); // reset all sequencers to step 0
        start_sequencers();
        noInterrupts(); // scenes change in the ISR so stop it running
        scene=0;  // start at first scene
        scenecounter=scenecount[scene];
        interrupts();
      }
      showposition(0); // update the screen in case sequencers are stopped
      startsongmode=true;      // so we only do this once per key hold
  }
  if (!(currtouched & TRANSPORT_BUTTON) && (lasttouched & TRANSPORT_BUTTON)) {  // transport button released   
    if ( tholdtime < TRANSPORT_BUTTON_HOLD_TIME) {
      play_mode=!play_mode;
      if (play_mode) start_sequencers();
      else stop_sequencers();
    }
  }

// process record button
  if ((currtouched & RECORD_BUTTON) && !(lasttouched & RECORD_BUTTON)) {  // record button pressed, start timing
    recbutton_timer=millis();
    trackerased=false;
  }
  uint32_t recholdtime=millis()-recbutton_timer;
  if ((currtouched & RECORD_BUTTON) && (recholdtime > RECBUTTON_HOLD_TIME) && !trackerased) { //record button held
    seq[track].removeNotes(scene <<4 | track); //  hold record to clear scene
//    allnotesoff(); // silence all notes that may have been playing
    trackerased=true; // if we keep erasing it causes audio noise
    if (topmenuindex < NTRACKS) showpattern(topmenuindex); // show the piano roll if this is a track menu
 //   Serial.printf("track erased\n");
  }
  if (!(currtouched & RECORD_BUTTON) && (lasttouched & RECORD_BUTTON)) {  // record button released   
    if ( recholdtime < RECBUTTON_HOLD_TIME) {
        record_mode=!record_mode;
    }
    showposition(0);  // update the screen in case sequencers are stopped
  }


// process copy button
  if ((currtouched & COPY_BUTTON) && !(lasttouched & COPY_BUTTON)) {  // copy button pressed
    if (currtouched & SCENE_BUTTON) copyscene(scene);
    else copyclip(track,scene);  
  }

// process paste button
  if ((currtouched & PASTE_BUTTON) && !(lasttouched & PASTE_BUTTON)) {  // paste button pressed
    if (currtouched & SCENE_BUTTON) pastescene(scene);
    else pasteclip(track,scene);  
  }

// debug
/*
  if ((currtouched & EXTRA_BUTTON) && !(lasttouched & EXTRA_BUTTON)) {  
    seq[track].dumpNotes();
  }
*/

// process number pads - note entry, track and scene select etc
  for (uint8_t i=0; i<NPADS; i++) { // have to scan all the pads because they are not in order
    if (padmap[i] < 16) { // process just the number pads
      if ((currtouched & _BV(i)) && !(lasttouched & _BV(i)) ) { // if pad was pressed
       // Serial.printf("numpad %d curtouched %04x %02x\n",padmap[i],currtouched, padA.touched());
        if ((currtouched & SCENE_BUTTON) && (!(currtouched & COPY_BUTTON)) && (!(currtouched & PASTE_BUTTON))) {
         // Serial.printf("scene \n");
          if (!edit_mode) scene=padmap[i];  // scene button + pad = change scene
          showpattern(track); // update piano roll for this scene
        }
        // else if ((currtouched & TRACK_BUTTON) && (!edit_mode)) { // track button + pad = change track
        else if ((padA.touched() & TRACK_BUTTON) && (!edit_mode)) { // track button + pad = change track
       // Serial.printf("track %d\n",padmap[i]);
          track=topmenuindex=padmap[i];  // *** kludgy - force menu to that track
          uistate=SUBSELECT; // do submenu when button is released
          topmenu[topmenuindex].submenuindex=0;  // start from the first item
          drawsubmenus();
          drawselector(topmenu[topmenuindex].submenuindex);
          showpattern(track); // update piano roll for this track
        }
        
        else { // use the keypad to enter notes
          if (voice[track].slices == 0) { // normal pitched playback
            voice[track].note=padtoMIDI[current_scale][padmap[i]];
            voice[track].velocity=DEFAULT_LEVEL;
          }
          else {  // slice playback mode
            voice[track].note=padmap[i]+MIDDLE_C;
          }
      // if recording, save note on
          if(record_mode) {
            seq[track].setNote(scene <<4 | track, voice[track].note, DEFAULT_LEVEL); // record note with fixed velocity
          //seq[track].dumpNotes();
          }  
          rp2040.fifo.push(((0x90 | track)<<24) | (DEFAULT_LEVEL <<16));  // tell other core to play this voice  
          showpattern(track);      
        }
      }
 /*  removed note offs - they just chew up memory
     if (!(currtouched & _BV(i)) && (lasttouched & _BV(i)) ) { // if pad just released
           // if recording, save note off
        if ((record_mode) && (voice[track].slices == 0)) seq[track].setNote(scene << 4 | track, padtoMIDI[current_scale][padmap[i]], 0x0); // pitch mode note off
        else seq[track].setNote(scene <<4 | track, padmap[i]+MIDDLE_C, 0); // slice mode note off
       
      } */
    }
  }

  lasttouched = currtouched; // reset pad state
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

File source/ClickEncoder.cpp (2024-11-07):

// ----------------------------------------------------------------------------
// Rotary Encoder Driver with Acceleration
// Supports Click, DoubleClick, Long Click
//
// (c) 2010 karl@pitrich.com
// (c) 2014 karl@pitrich.com
//
// Timer-based rotary encoder logic by Peter Dannegger
// http://www.mikrocontroller.net/articles/Drehgeber
// ----------------------------------------------------------------------------

#include "ClickEncoder.h"

// ----------------------------------------------------------------------------
// Button configuration (values for 1ms timer service calls)
//
#define ENC_BUTTONINTERVAL    10  // check button every x milliseconds, also debouce time
//#define ENC_DOUBLECLICKTIME  800  // second click within 00ms
#define ENC_DOUBLECLICKTIME  100  // second click within 00ms - RH keeping short for Groovebox because I'm not using doubleclick
#define ENC_HOLDTIME        500  // report held button after .5s

// ----------------------------------------------------------------------------
// Acceleration configuration (for 1000Hz calls to ::service())
//
#define ENC_ACCEL_TOP      3072   // max. acceleration: *12 (val >> 8)
#define ENC_ACCEL_INC        50
#define ENC_ACCEL_DEC         2

// ----------------------------------------------------------------------------

#if ENC_DECODER != ENC_NORMAL
#  ifdef ENC_HALFSTEP
     // decoding table for hardware with flaky notch (half resolution)
     const int8_t ClickEncoder::table[16] __attribute__((__progmem__)) = {
       0, 0, -1, 0, 0, 0, 0, 1, 1, 0, 0, 0, 0, -1, 0, 0
     };
#  else
     // decoding table for normal hardware
     const int8_t ClickEncoder::table[16] __attribute__((__progmem__)) = {
       0, 1, -1, 0, -1, 0, 0, 1, 1, 0, 0, -1, 0, -1, 1, 0
     };
#  endif
#endif

// ----------------------------------------------------------------------------

ClickEncoder::ClickEncoder(uint8_t A, uint8_t B, uint8_t BTN, uint8_t stepsPerNotch, bool active)
  : doubleClickEnabled(true), accelerationEnabled(true),
    delta(0), last(0), acceleration(0),
    button(Open), steps(stepsPerNotch),
    pinA(A), pinB(B), pinBTN(BTN), pinsActive(active)
{
  uint8_t configType = (pinsActive == LOW) ? INPUT_PULLUP : INPUT;
  pinMode(pinA, configType);
  pinMode(pinB, configType);
  pinMode(pinBTN, configType);

  if (digitalRead(pinA) == pinsActive) {
    last = 3;
  }

  if (digitalRead(pinB) == pinsActive) {
    last ^=1;
  }
}

// ----------------------------------------------------------------------------
// call this every 1 millisecond via timer ISR
//
void ClickEncoder::service(void)
{
  bool moved = false;
  unsigned long now = millis();

  if (accelerationEnabled) { // decelerate every tick
    acceleration -= ENC_ACCEL_DEC;
    if (acceleration & 0x8000) { // handle overflow of MSB is set
      acceleration = 0;
    }
  }

#if ENC_DECODER == ENC_FLAKY
  last = (last << 2) & 0x0F;

  if (digitalRead(pinA) == pinsActive) {
    last |= 2;
  }

  if (digitalRead(pinB) == pinsActive) {
    last |= 1;
  }

  uint8_t tbl = pgm_read_byte(&table[last]);
  if (tbl) {
    delta += tbl;
    moved = true;
  }
#elif ENC_DECODER == ENC_NORMAL
  int8_t curr = 0;

  if (digitalRead(pinA) == pinsActive) {
    curr = 3;
  }

  if (digitalRead(pinB) == pinsActive) {
    curr ^= 1;
  }

  int8_t diff = last - curr;

  if (diff & 1) {            // bit 0 = step
    last = curr;
    delta += (diff & 2) - 1; // bit 1 = direction (+/-)
    moved = true;
  }
#else
# error "Error: define ENC_DECODER to ENC_NORMAL or ENC_FLAKY"
#endif

  if (accelerationEnabled && moved) {
    // increment accelerator if encoder has been moved
    if (acceleration <= (ENC_ACCEL_TOP - ENC_ACCEL_INC)) {
      acceleration += ENC_ACCEL_INC;
    }
  }

  // handle button
  //
#ifndef WITHOUT_BUTTON
  if (pinBTN > 0 // check button only, if a pin has been provided
      && (now - lastButtonCheck) >= ENC_BUTTONINTERVAL) // checking button is sufficient every 10-30ms
  {
    lastButtonCheck = now;

    if (digitalRead(pinBTN) == pinsActive) { // key is down
      button=Closed;
      keyDownTicks++;
      if (keyDownTicks > (ENC_HOLDTIME / ENC_BUTTONINTERVAL)) {
        button = Held;
      }
    }

    if (digitalRead(pinBTN) == !pinsActive) { // key is now up
      if (keyDownTicks /*> ENC_BUTTONINTERVAL*/) {
        if (button == Held) {
          button = Released;
          doubleClickTicks = 0;
        }
        else {
          #define ENC_SINGLECLICKONLY 1
          if (doubleClickTicks > ENC_SINGLECLICKONLY) {   // prevent trigger in single click mode
            if (doubleClickTicks < (ENC_DOUBLECLICKTIME / ENC_BUTTONINTERVAL)) {
              button = DoubleClicked;
              doubleClickTicks = 0;
            }
          }
          else {
            doubleClickTicks = (doubleClickEnabled) ? (ENC_DOUBLECLICKTIME / ENC_BUTTONINTERVAL) : ENC_SINGLECLICKONLY;
          }
        }
      }

      keyDownTicks = 0;
    }

    if (doubleClickTicks > 0) {
      doubleClickTicks--;
      if (--doubleClickTicks == 0) {
        button = Clicked;
      }
    }
  }
#endif // WITHOUT_BUTTON

}

// ----------------------------------------------------------------------------

int16_t ClickEncoder::getValue(void)
{
  int16_t val;

  cli();
  val = delta;

  if (steps == 2) delta = val & 1;
  else if (steps == 4) delta = val & 3;
  else delta = 0; // default to 1 step per notch

  sei();

  if (steps == 4) val >>= 2;
  if (steps == 2) val >>= 1;

  int16_t r = 0;
  int16_t accel = ((accelerationEnabled) ? (acceleration >> 8) : 0);

  if (val < 0) {
    r -= 1 + accel;
  }
  else if (val > 0) {
    r += 1 + accel;
  }

  return r;
}

// ----------------------------------------------------------------------------

#ifndef WITHOUT_BUTTON
ClickEncoder::Button ClickEncoder::getButton(void)
{
  ClickEncoder::Button ret = button;
  if (button != ClickEncoder::Held) {
    button = ClickEncoder::Open; // reset
  }
  return ret;
}
#endif

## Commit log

2024-10-27 Initial commit
    Groovebox based on RP2350
    [keypad.brd, keypad.sch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]
2024-11-04 Fixed .wav loader, added autorandomizer
    Fixed crash loading to .wav files, added autorandomizer feature
    [Pico2_Groovebox.ino, menusystem.h]
2024-11-07 Added Step Editor
    Added a step editor. F1 key to enter/exit editor. Turn encoder to change step, press encoder to toggle step editing
2025-10-07 SDIO and 3D printed enclosure, step editor
    This version has switched the SD card interface to SDIO for speed. stl files for a 3D printed enclosure are included. A step editor has been added to the software along with a lot of other fixes and enhancements
    [Base.stl, Top.stl]

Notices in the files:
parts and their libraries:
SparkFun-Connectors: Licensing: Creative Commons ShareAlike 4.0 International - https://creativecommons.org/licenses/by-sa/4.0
